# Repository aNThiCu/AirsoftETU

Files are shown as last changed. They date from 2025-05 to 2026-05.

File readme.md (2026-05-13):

Latest board is very promising , i have semi-abandoned the idea of separating the controls and power components from the sensors. The board is now a 4 layer consisting of GND-3.3V-GND-GND copper pours.
Pcb manufacturing at home sadly cannot fullfill my needs for this project , future versions will not be able to be manufactured in house as i have finished some of the testing needed for a complete product.

This revision still is in no way usable , as i haven't been able to test any of the new software implementations. I just finished the firmware and i am about to go on with assembling the rest of the PCB.
I've been using a board with no power electronics until now for testing the signal complementarity and overall logic of the system.

Hardware changes made from the last readme update:

 - added back the high side pmos , board cannot function without it as freewheel diode would blow
 - added back the mode selector phototransistors and led-added a schmitt trigger for hardware debounce
 - added proper gate drivers , MCP1416T-E
 - added some ESD protection diodes on the gates of the power FETS and 12v power rail
 - moved leds to the 3.3v rail
 - modified shape of PCB for better fitment

Software changes made from the last readme update:
   - configurable duty cycle, not tested actual usable range , over 90% is considered 100% due to dead_time limitations
   - configurable dead time ticks for pwm , 1 tick = 200ns , good for different types of power mosfets
   - implemented synchronous rectification to take the burden off the flywheel diode 
   - changed driving logic to permit both PWM and on/off
   - added burst mode capability
   - changed to platformio

What's coming next:
   - finishing testing with new pcb and firmware
   - troubleshooting indicators, buzzer for quick configs in the upcoming settings tab
   - folder with everything needed for direct manufacturing from a factory
   - might do a different type of trigger , either optical of magnetic , for longevity sake , i like the clicking feel of microswitches more though
   
What's been marked done from last readme update:
   - configurable mode selector switch with multiple modes
   - redo of shape for better fitment in V2 gearboxes

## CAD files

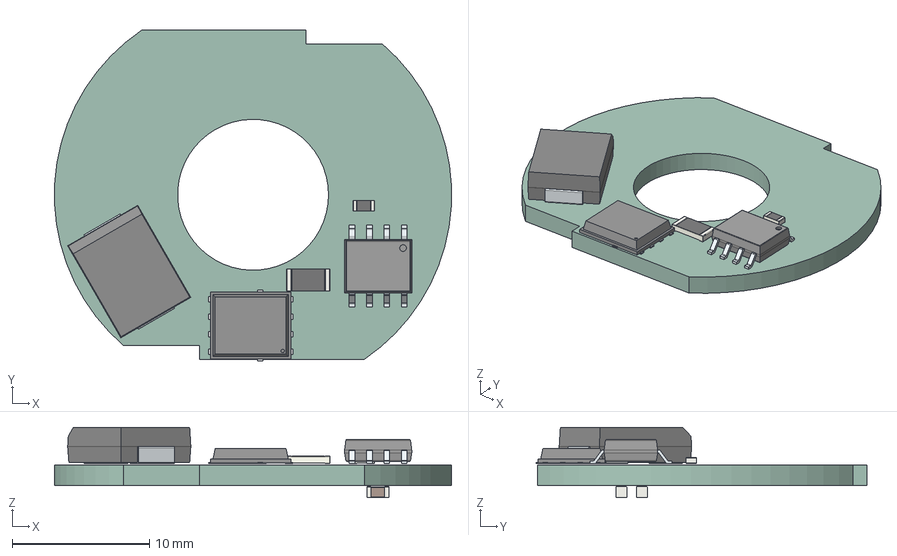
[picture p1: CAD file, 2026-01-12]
PCB_Files/ElectronicTriggerUnit.step
28.9 x 24.1 x 5.13 mm
PinsArrayLR
R_1206_3216Metric
SI7149ADP-T1-GE3
R_0603_1608Metric
FilletPin1
FilletPin2
C_0603_1608Metric x 2
ElectronicTriggerUnit_PCB

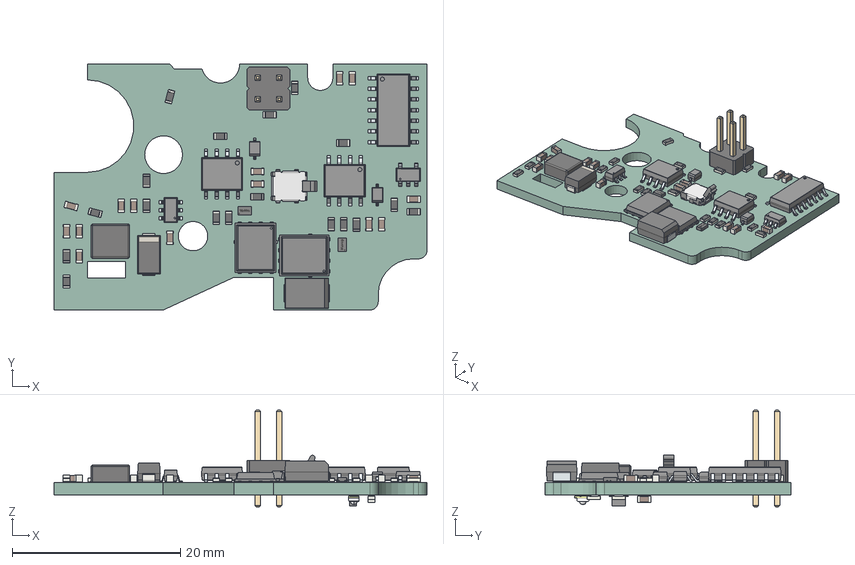
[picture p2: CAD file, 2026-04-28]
PCB_Files/ETU_AIO/ETU_AIO.step
44.4 x 29.3 x 11.5 mm
FilletPinL x 2
FilletPinR x 2
C_0603_1608Metric x 15
R_0603_1608Metric x 20
PinsArrayLR x 4
FilletPin1
FilletPin2
SI7149ADP-T1-GE3 x 2
pins x 14
housing x 2
JJDVDUJ314NCPMRTR
PinsArrayL
PinsArrayR
D_SMA
PinHeader_2x02_P2.54mm_Vertical
L_Chilisin_BMRA00040420
APTD2012SF4C
Pins
ETU_AIO_PCB

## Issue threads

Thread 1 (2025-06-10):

Questions about ETU development

DaniyalV1, 2025-06-10:
Hi there! @aNThiCu

I recently decided to make my own ETU for my CM16 Wildhog GnG Airsoft replica (Version 2 gearbox). I saw that after the "main" section, you continued developing the ETU.

- I know you are still not done, but could you please tell me the issues you have encountered so far?
- I have a LONEX A3 motor, and it falls under the Low TPA category. Does this mean I can't use my motor at all?
- Why did you decide to use sensors inside the gearbox rather than switches? My gearbox currently has tiny switches for the trigger, and replacing them would make it very hard in terms of redesigning the trigger mechanism, etc.
- What is the state of the project?

I would like to further work on this project, and we could collaborate if you would like to.

Thank you!

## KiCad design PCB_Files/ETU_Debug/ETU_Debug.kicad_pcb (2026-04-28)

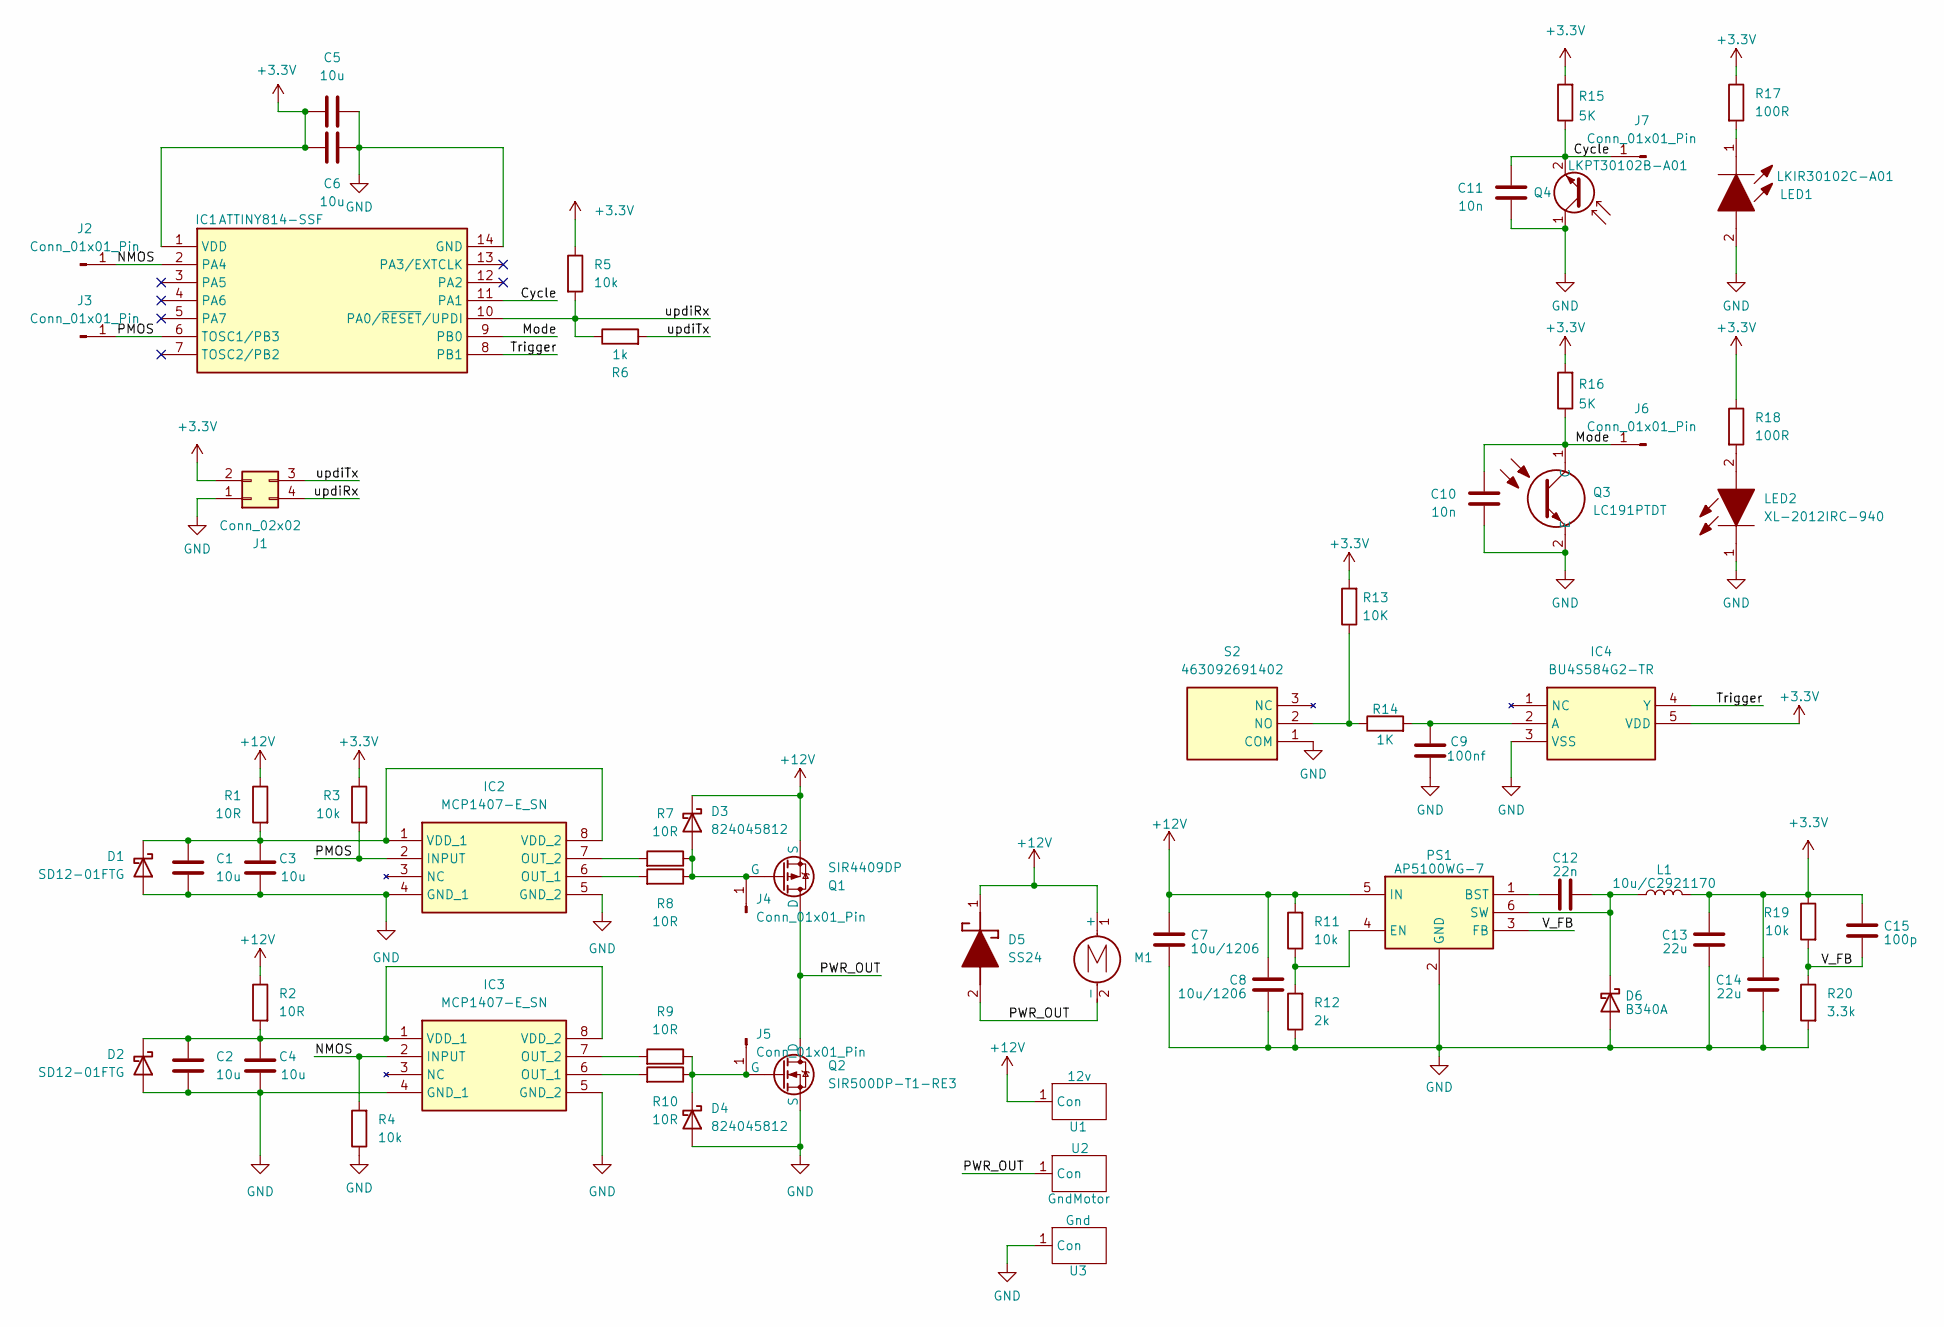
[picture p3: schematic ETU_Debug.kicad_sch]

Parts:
C1, C2, C3, C4, C5, C6: 10u; C_0603_1608Metric
C7, C8: 10u/1206; C_0603_1608Metric; MPN C13585
C9: 100nf; C_0603_1608Metric
C10, C11: 10n; C_0603_1608Metric
C12: 22n; C_0603_1608Metric; MPN C21122
C13, C14: 22u; C_0603_1608Metric; MPN C45783
C15: 100p; C_0603_1608Metric; MPN C1790
D1, D2: SD12-01FTG; SOD2613X114N
D3, D4: 824045812
D5: SS24; DIOM5436X247N; Mouser Part Number 821-SS24
D6: B340A; D_SMA; MPN C3018525
IC1: ATTINY814-SSF; SOIC127P600X175-14N; Mouser Part Number 579-ATTINY814-SSF
IC2, IC3: MCP1407-E_SN; SOIC127P600X175-8N; Mouser Part Number 579-MCP1407-E/SN
IC4: BU4S584G2-TR; SOT95P280X125-5N; Mouser Part Number 755-BU4S584G2-TR
J1: Conn_02x02; PinHeader_2x02_P2.54mm_Vertical
J2, J3, J4, J5, J6, J7: Conn_01x01_Pin; PinHeader_1x01_P2.54mm_Vertical
L1: 10u/C2921170; L_Chilisin_BMRA00040420; MPN C2921170
LED1: LKIR30102C-A01; APA3010P3C; Mouser Part Number 755-CSL1501RW1
LED2: XL-2012IRC-940; LEDC2012X105N; Mouser Part Number 604-APTD2012SF4C
M1: Motor_DC
PS1: AP5100WG-7; SOT95P285X140-6N; Mouser Part Number 621-AP5100WG-7
Q1: SIR4409DP; POWERPAKSO-8
Q2: SIR500DP-T1-RE3; POWERPAKSO-8
Q3: LC191PTDT; AP1608P1CP22; Mouser Part Number 604-AP1608P1C-P22
Q4: LKPT30102B-A01; APA3010P3C
R1, R2, R7, R8, R9, R10: 10R; R_0603_1608Metric
R3, R4, R5: 10k; R_0603_1608Metric
R6: 1k; R_0603_1608Metric
R11, R19: 10k; R_0603_1608Metric; MPN C25804
R12: 2k; R_0603_1608Metric; MPN C22975
R13: 10K; R_0603_1608Metric
R14: 1K; R_0603_1608Metric
R15, R16: 5K; R_0603_1608Metric
R17, R18: 100R; R_0603_1608Metric
R20: 3.3k; R_0603_1608Metric; MPN C22975
S2: 463092691402; Mouser Part Number 710-463092691402
U1: 12v; Copper_Pad
U2: GndMotor; Copper_Pad
U3: Gnd; Copper_Pad

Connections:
+3.3V: C5.1, C6.1, C13.1, C14.1, C15.1, IC1.1 (VDD), IC4.5 (VDD), J1.2, L1.2, R3.1, R5.1, R13.2, R15.2, R16.2, R17.1, R18.1, R19.1
+12V: C7.1, C8.1, D3.1 (K), D5.1 (K), M1.1 (+), PS1.5 (IN), Q1.1 (S), Q1.2 (S), Q1.3 (S), R1.1, R2.1, R11.2, U1.1 (Con)
/Cycle: C11.1, IC1.11 (PA1), J7.1, Q4.2 (E), R15.1
/Mode: C10.1, IC1.9 (PB0), J6.1, Q3.1 (C), R16.1
/NMOS: IC1.2 (PA4), IC3.2 (INPUT), J2.1, R4.2
/PMOS: IC1.6 (TOSC1/PB3), IC2.2 (INPUT), J3.1, R3.2
/PWR_OUT: D5.2 (A), M1.2 (-), Q1.5 (D), Q1.6 (D), Q1.7 (D), Q1.8 (D), Q1.9 (D), Q2.5 (D), Q2.6, Q2.7, Q2.8, Q2.9, U2.1 (Con)
/Trigger: IC1.8 (PB1), IC4.4 (Y)
/V_FB: C15.2, PS1.3 (FB), R19.2, R20.1
/updiRx: IC1.10 (PA0/~RESET/UPDI), J1.4, R5.2, R6.1
/updiTx: J1.3, R6.2
GND: C1.2, C2.2, C3.1, C4.1, C5.2, C6.2, C7.2, C8.2, C9.1, C10.2, C11.2, C13.2, C14.2, D1.2 (A), D2.2 (A), D4.2 (A), D6.2 (A), IC1.14 (GND), IC2.4 (GND_1), IC2.5 (GND_2), IC3.4 (GND_1), IC3.5 (GND_2), IC4.3 (VSS), J1.1, LED1.2, LED2.1, PS1.2 (GND), Q2.1 (S), Q2.2, Q2.3, Q3.2 (E), Q4.1 (C), R4.1, R12.1, R20.2, S2.1 (COM), U3.1 (Con)
unnamed: C1.1, C3.2, D1.1 (K), IC2.1 (VDD_1), IC2.8 (VDD_2), R1.2
unnamed: C2.1, C4.2, D2.1 (K), IC3.1 (VDD_1), IC3.8 (VDD_2), R2.2
unnamed: D3.2 (A), J4.1, Q1.4 (G), R7.1, R8.1
unnamed: D4.1 (K), J5.1, Q2.4 (G), R9.1, R10.1
unnamed: C12.2, D6.1 (K), L1.1, PS1.6 (SW)
unnamed: IC2.6 (OUT_1), R8.2
unnamed: IC2.7 (OUT_2), R7.2
unnamed: IC3.6 (OUT_1), R10.2
unnamed: IC3.7 (OUT_2), R9.2
unnamed: C9.2, IC4.2 (A), R14.2
unnamed: LED1.1, R17.2
unnamed: LED2.2, R18.2
unnamed: C12.1, PS1.1 (BST)
unnamed: PS1.4 (EN), R11.1, R12.2
unnamed: R13.1, R14.1, S2.2 (NO)

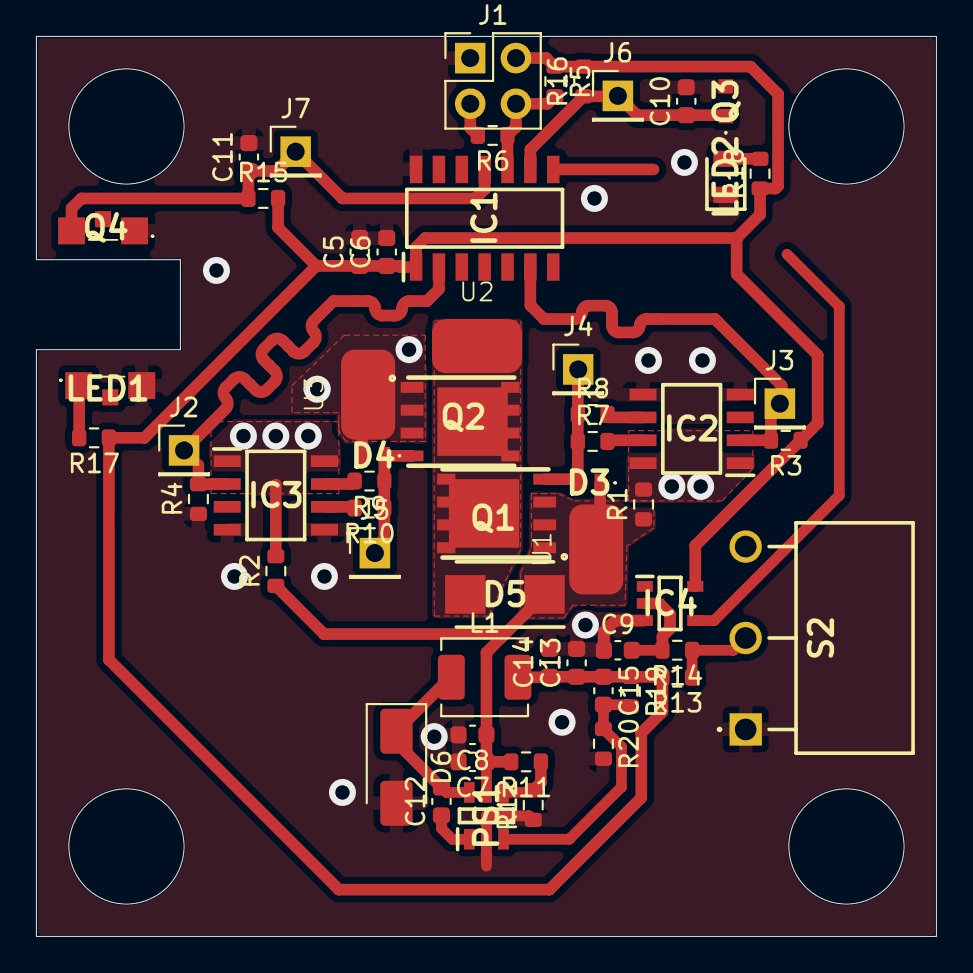
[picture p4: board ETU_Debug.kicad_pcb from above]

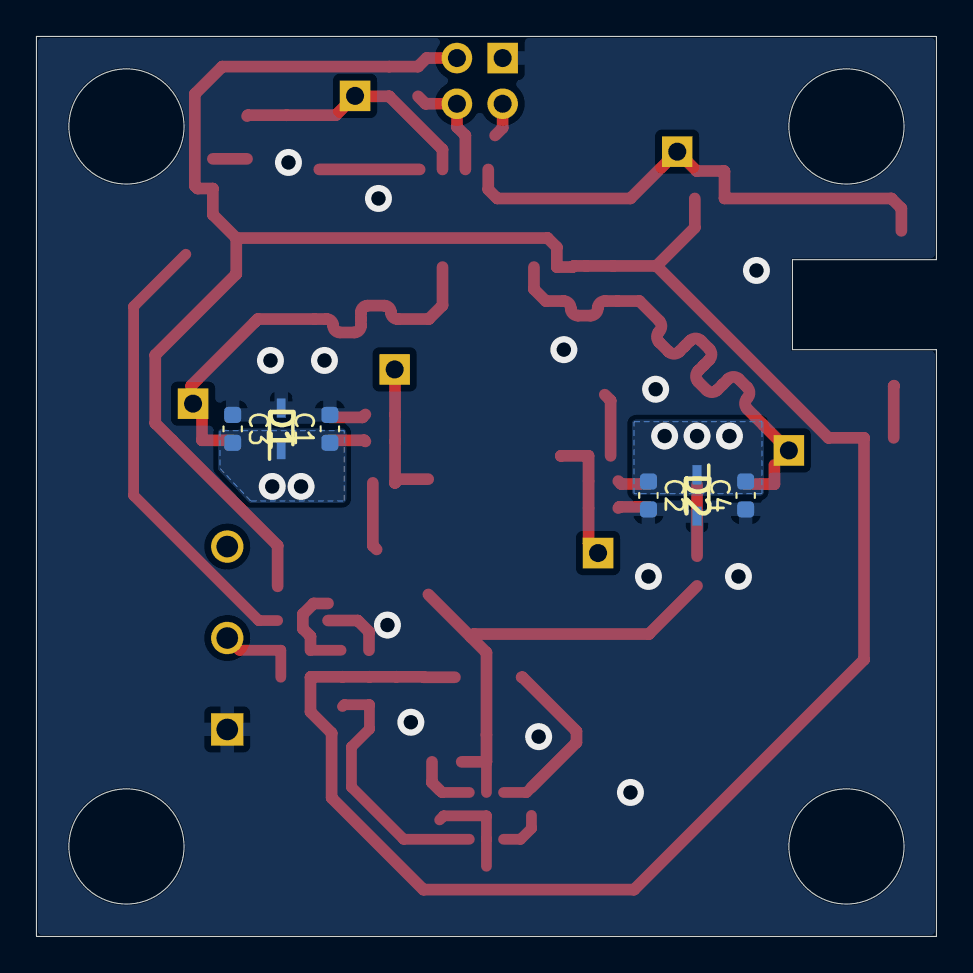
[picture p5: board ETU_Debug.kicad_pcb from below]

Board: 2 copper layers, 50.0 x 50.0 mm, 64 parts (6 on the bottom side), 27 nets.

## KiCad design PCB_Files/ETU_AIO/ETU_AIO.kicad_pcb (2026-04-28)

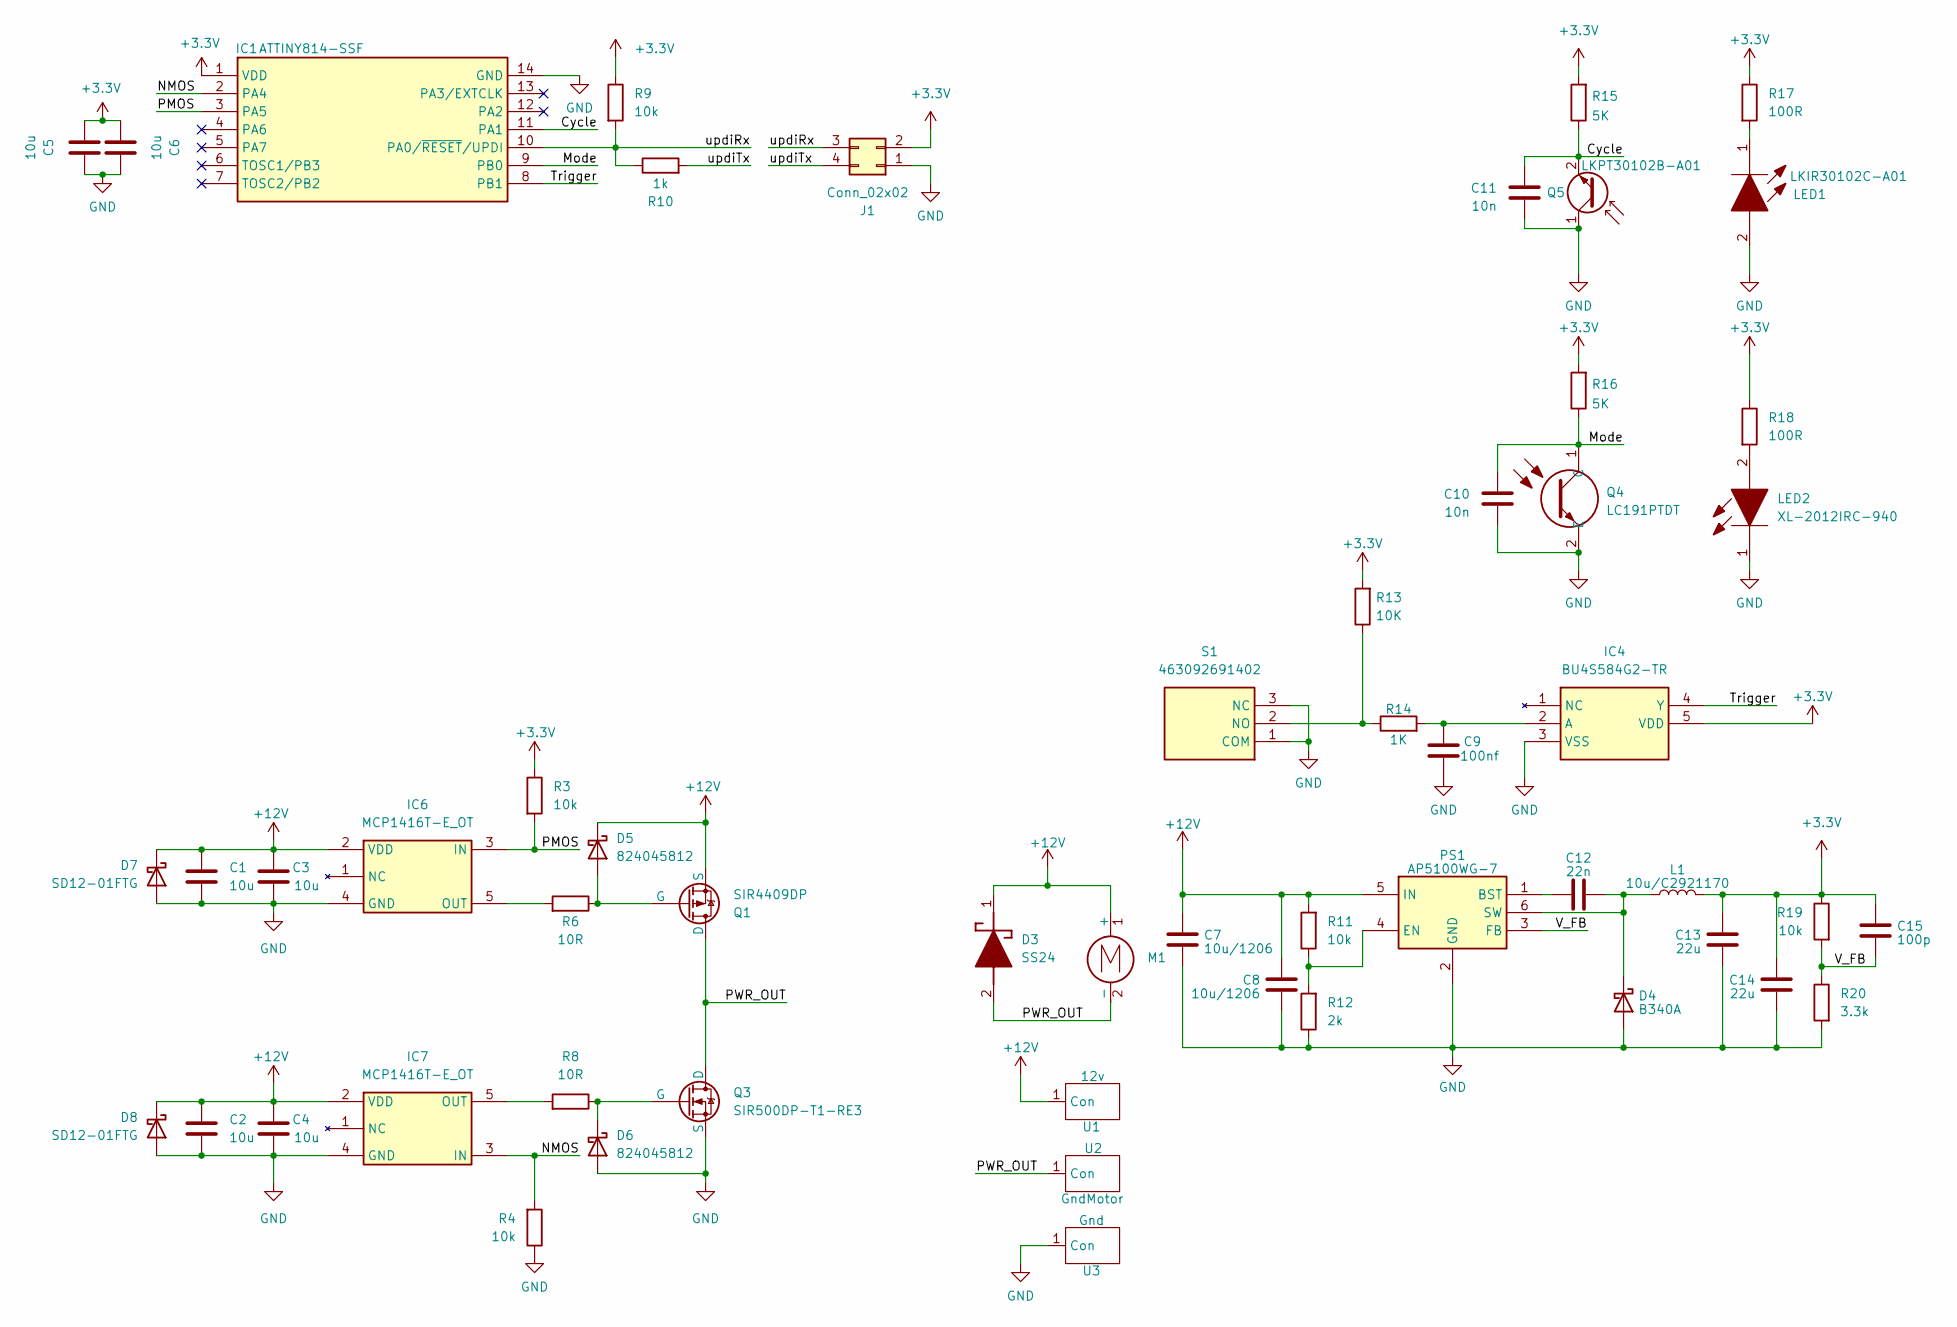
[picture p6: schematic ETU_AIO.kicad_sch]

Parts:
C1, C2, C3, C4, C5, C6: 10u; C_0603_1608Metric
C7, C8: 10u/1206; C_0603_1608Metric; MPN C13585
C9: 100nf; C_0603_1608Metric
C10, C11: 10n; C_0603_1608Metric
C12: 22n; C_0603_1608Metric; MPN C21122
C13, C14: 22u; C_0603_1608Metric; MPN C45783
C15: 100p; C_0603_1608Metric; MPN C1790
D3: SS24; DIOM5436X247N; Mouser Part Number 821-SS24
D4: B340A; D_SMA; MPN C3018525
D5, D6: 824045812
D7, D8: SD12-01FTG; SOD2613X114N
IC1: ATTINY814-SSF; SOIC127P600X175-14N; Mouser Part Number 579-ATTINY814-SSF
IC4: BU4S584G2-TR; SOT95P280X125-5N; Mouser Part Number 755-BU4S584G2-TR
IC6, IC7: MCP1416T-E_OT; SOT95P270X145-5N; Mouser Part Number 579-MCP1416T-E/OT
J1: Conn_02x02; PinHeader_1x04_P2.54mm_Vertical
L1: 10u/C2921170; L_Chilisin_BMRA00040420; MPN C2921170
LED1: LKIR30102C-A01; APA3010P3C; Mouser Part Number 755-CSL1501RW1
LED2: XL-2012IRC-940; LEDC2012X105N; Mouser Part Number 604-APTD2012SF4C
M1: Motor_DC
PS1: AP5100WG-7; SOT95P285X140-6N; Mouser Part Number 621-AP5100WG-7
Q1: SIR4409DP; POWERPAKSO-8
Q3: SIR500DP-T1-RE3; POWERPAKSO-8
Q4: LC191PTDT; AP1608P1CP22; Mouser Part Number 604-AP1608P1C-P22
Q5: LKPT30102B-A01; APA3010P3C
R3, R4, R9: 10k; R_0603_1608Metric
R6, R8: 10R; R_0603_1608Metric
R10: 1k; R_0603_1608Metric
R11, R19: 10k; R_0603_1608Metric; MPN C25804
R12: 2k; R_0603_1608Metric; MPN C22975
R13: 10K; R_0603_1608Metric
R14: 1K; R_0603_1608Metric
R15, R16: 5K; R_0603_1608Metric
R17, R18: 100R; R_0603_1608Metric
R20: 3.3k; R_0603_1608Metric; MPN C22975
S1: 463092691402; Mouser Part Number 710-463092691402
U1: 12v; Copper_Pad
U2: GndMotor; Copper_Pad
U3: Gnd; Copper_Pad

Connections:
+3.3V: C5.1, C6.1, C13.1, C14.1, C15.1, IC1.1 (VDD), IC4.5 (VDD), J1.2, L1.2, R3.1, R9.1, R13.2, R15.2, R16.2, R17.1, R18.1, R19.1
+12V: C1.1, C2.1, C3.2, C4.2, C7.1, C8.1, D3.1 (K), D5.1 (K), D7.1 (K), D8.1 (K), IC6.2 (VDD), IC7.2 (VDD), M1.1 (+), PS1.5 (IN), Q1.1 (S), Q1.2 (S), Q1.3 (S), R11.2, U1.1 (Con_1)
/Cycle: C11.1, IC1.11 (PA1), Q5.2 (E), R15.1
/Mode: C10.1, IC1.9 (PB0), Q4.1 (C), R16.1
/NMOS: IC1.2 (PA4), IC7.3 (IN), R4.2
/PMOS: IC1.3 (PA5), IC6.3 (IN), R3.2
/PWR_OUT: D3.2 (A), M1.2 (-), Q1.5 (D), Q1.6 (D), Q1.7 (D), Q1.8 (D), Q1.9 (D), Q3.5 (D), Q3.6, Q3.7, Q3.8, Q3.9, U2.1 (Con_1)
/Trigger: IC1.8 (PB1), IC4.4 (Y)
/V_FB: C15.2, PS1.3 (FB), R19.2, R20.1
/updiRx: IC1.10 (PA0/~RESET/UPDI), J1.3, R9.2, R10.1
/updiTx: J1.4, R10.2
GND: C1.2, C2.2, C3.1, C4.1, C5.2, C6.2, C7.2, C8.2, C9.1, C10.2, C11.2, C13.2, C14.2, D4.2 (A), D6.2 (A), D7.2 (A), D8.2 (A), IC1.14 (GND), IC4.3 (VSS), IC6.4 (GND), IC7.4 (GND), J1.1, LED1.2, LED2.1, PS1.2 (GND), Q3.1 (S), Q3.2, Q3.3, Q4.2 (E), Q5.1 (C), R4.1, R12.1, R20.2, S1.1 (COM), S1.3 (NC), U3.1 (Con_1)
unnamed: C12.2, D4.1 (K), L1.1, PS1.6 (SW)
unnamed: D5.2 (A), Q1.4 (G), R6.1
unnamed: D6.1 (K), Q3.4 (G), R8.1
unnamed: C9.2, IC4.2 (A), R14.2
unnamed: IC6.5 (OUT), R6.2
unnamed: IC7.5 (OUT), R8.2
unnamed: LED1.1, R17.2
unnamed: LED2.2, R18.2
unnamed: C12.1, PS1.1 (BST)
unnamed: PS1.4 (EN), R11.1, R12.2
unnamed: R13.1, R14.1, S1.2 (NO)

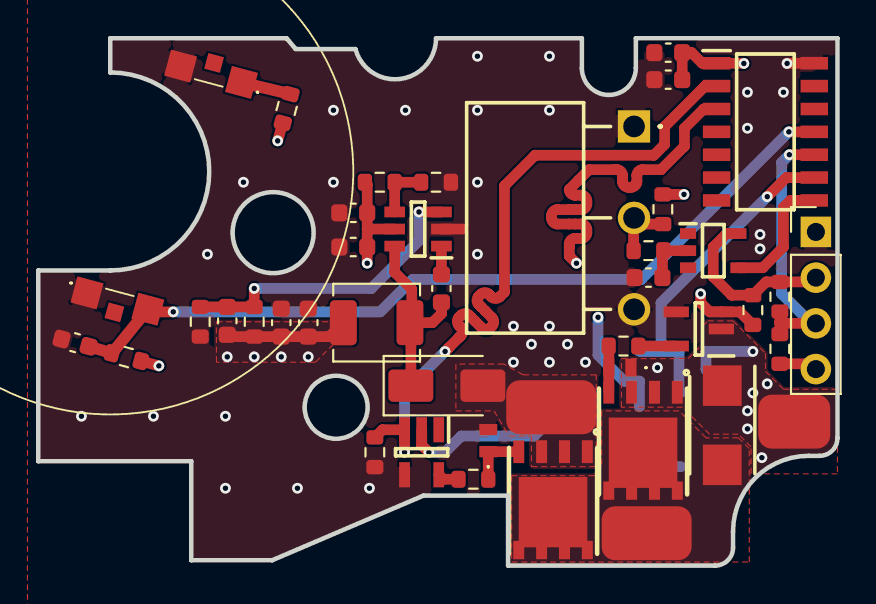
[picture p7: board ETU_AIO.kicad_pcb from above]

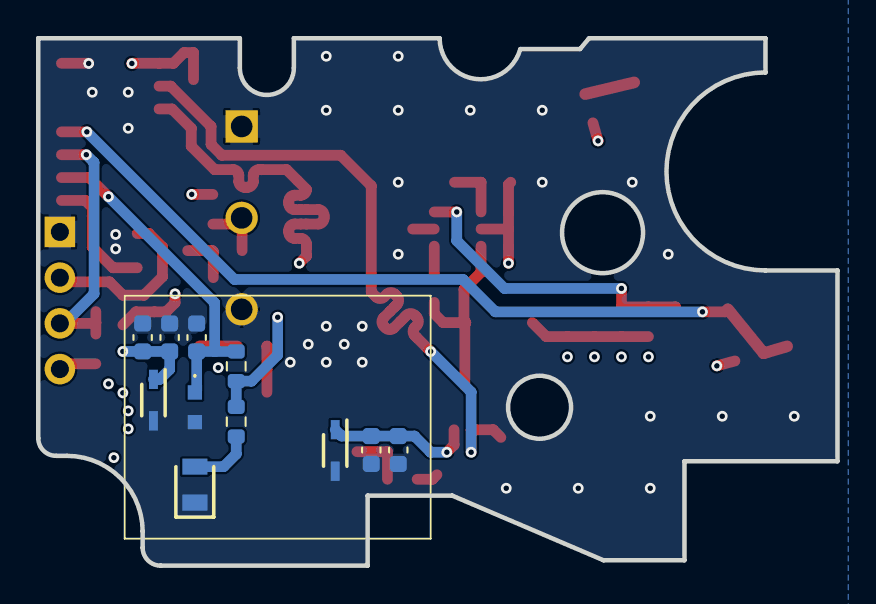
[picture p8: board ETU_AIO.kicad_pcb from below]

Board: 4 copper layers, 44.4 x 29.3 mm, 54 parts (11 on the bottom side), 23 nets.

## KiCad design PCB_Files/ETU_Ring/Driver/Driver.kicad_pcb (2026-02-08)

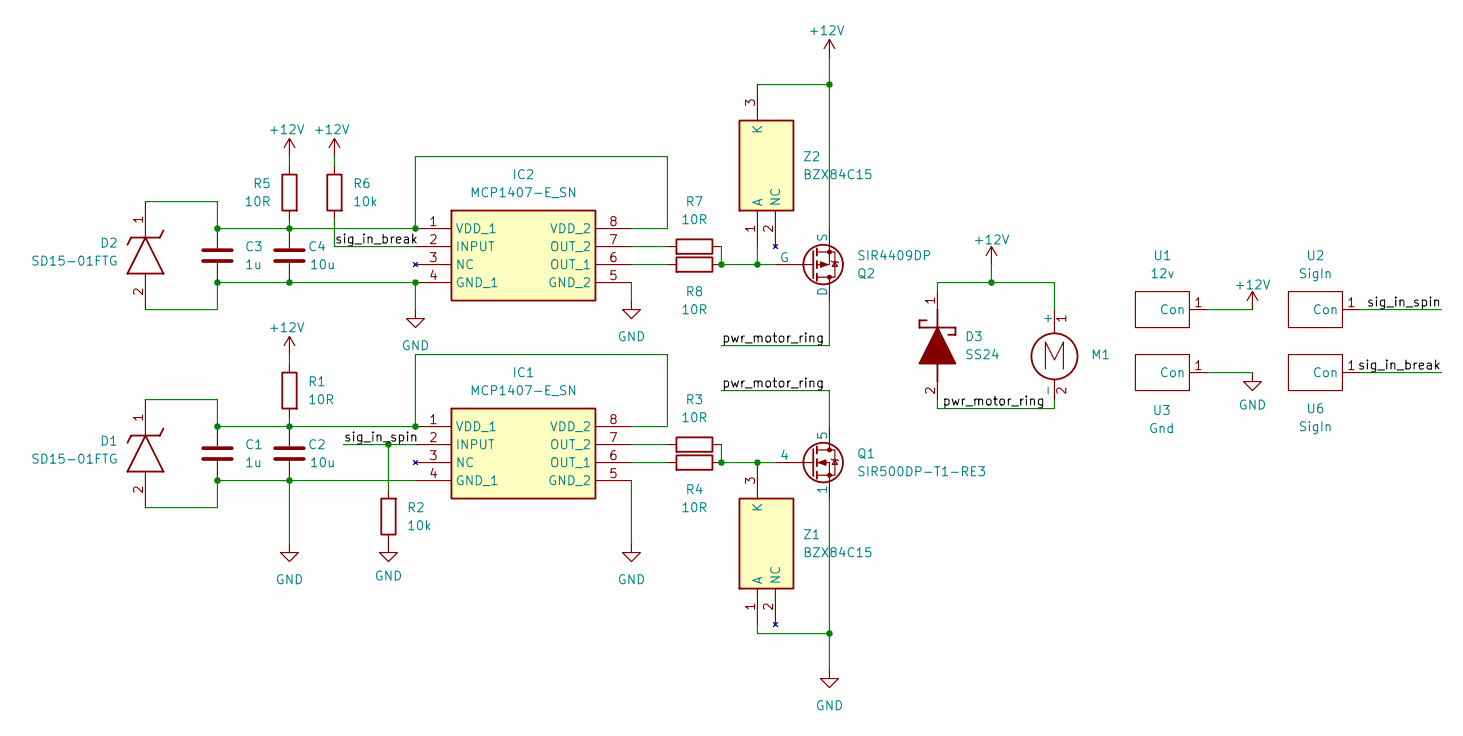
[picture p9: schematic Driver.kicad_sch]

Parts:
C1, C3: 1u; C_0603_1608Metric
C2, C4: 10u; C_0603_1608Metric
D1, D2: SD15-01FTG; SOD2613X114N; Manufacturer_Part_Number SD15-01FTG
D3: SS24; DIOM5436X247N; Mouser Part Number 821-SS24
IC1, IC2: MCP1407-E_SN; SOIC127P600X175-8N; Mouser Part Number 579-MCP1407-E/SN
M1: Motor_DC
Q1: SIR500DP-T1-RE3; POWERPAKSO-8
Q2: SIR4409DP; POWERPAKSO-8
R1, R3, R4, R5, R7, R8: 10R; R_0603_1608Metric
R2, R6: 10k; R_0603_1608Metric
U1: 12v; Copper_Pad
U2, U6: SigIn; Copper_Pad
U3: Gnd; Copper_Pad
Z1, Z2: BZX84C15; SOT96P260X140-3N; Manufacturer_Part_Number BZX84C15

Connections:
+12V: D3.1 (K), M1.1 (+), Q2.1 (S), Q2.2 (S), Q2.3 (S), R1.1, R5.1, R6.1, U1.1 (Con), Z2.2 (NC), Z2.3 (K)
/pwr_motor_ring: D3.2 (A), M1.2 (-), Q1.5, Q1.6, Q1.7, Q1.8, Q1.9, Q2.5 (D), Q2.6 (D), Q2.7 (D), Q2.8 (D), Q2.9 (D)
/sig_in_break: IC2.2 (INPUT), R6.2, U6.1 (Con)
/sig_in_spin: IC1.2 (INPUT), R2.2, U2.1 (Con)
GND: C1.2, C2.1, C3.2, C4.1, D1.2 (A), D2.2 (A), IC1.4 (GND_1), IC1.5 (GND_2), IC2.4 (GND_1), IC2.5 (GND_2), Q1.1, Q1.2, Q1.3, R2.1, U3.1 (Con), Z1.1 (A)
unnamed: C1.1, C2.2, D1.1 (K), IC1.1 (VDD_1), IC1.8 (VDD_2), R1.2
unnamed: C3.1, C4.2, D2.1 (K), IC2.1 (VDD_1), IC2.8 (VDD_2), R5.2
unnamed: IC1.6 (OUT_1), R4.2
unnamed: IC1.7 (OUT_2), R3.2
unnamed: IC2.6 (OUT_1), R8.2
unnamed: IC2.7 (OUT_2), R7.2
unnamed: Q2.4 (G), R7.1, R8.1, Z2.1 (A)
unnamed: Q1.4, R3.1, R4.1, Z1.3 (K)

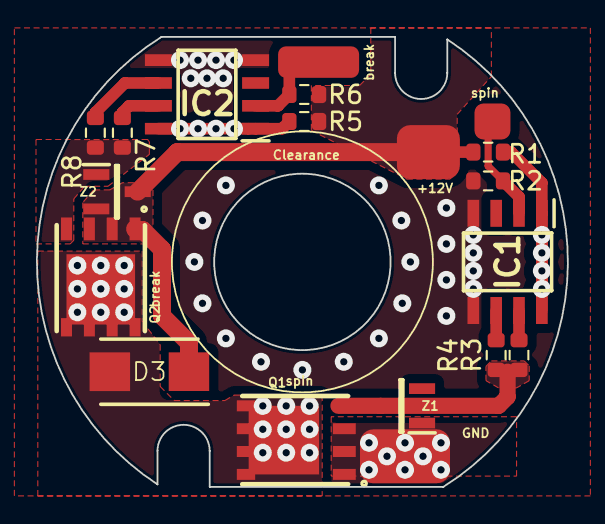
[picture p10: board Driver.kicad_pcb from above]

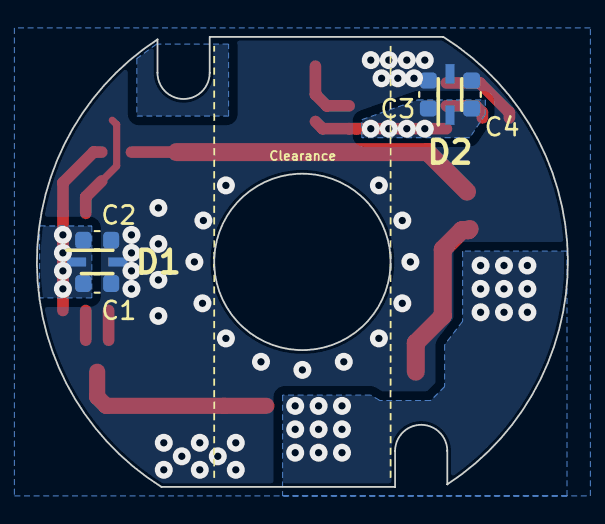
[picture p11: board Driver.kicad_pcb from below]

Board: 2 copper layers, 29.5 x 25.0 mm, 25 parts (6 on the bottom side), 13 nets.

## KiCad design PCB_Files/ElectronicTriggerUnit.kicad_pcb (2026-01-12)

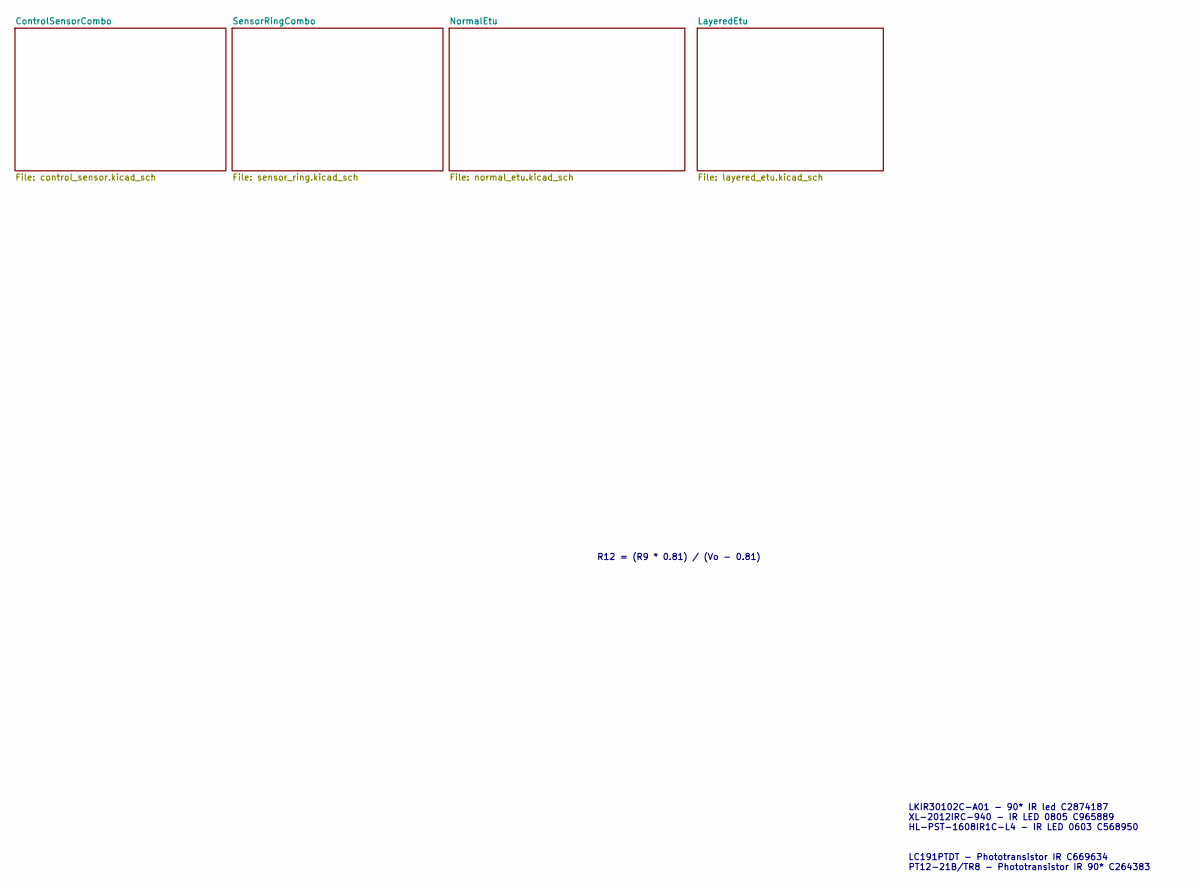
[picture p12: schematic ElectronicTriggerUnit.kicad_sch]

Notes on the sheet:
R12 = (R9 * 0.81) / (Vo - 0.81)
LKIR30102C-A01 - 90* IR led C2874187 XL-2012IRC-940 - IR LED 0805 C965889 HL-PST-1608IR1C-L4 - IR LED 0603 C568950 LC191PTDT - Phototransistor IR C669634 PT12-21B/TR8 - Phototransistor IR 90* C264383

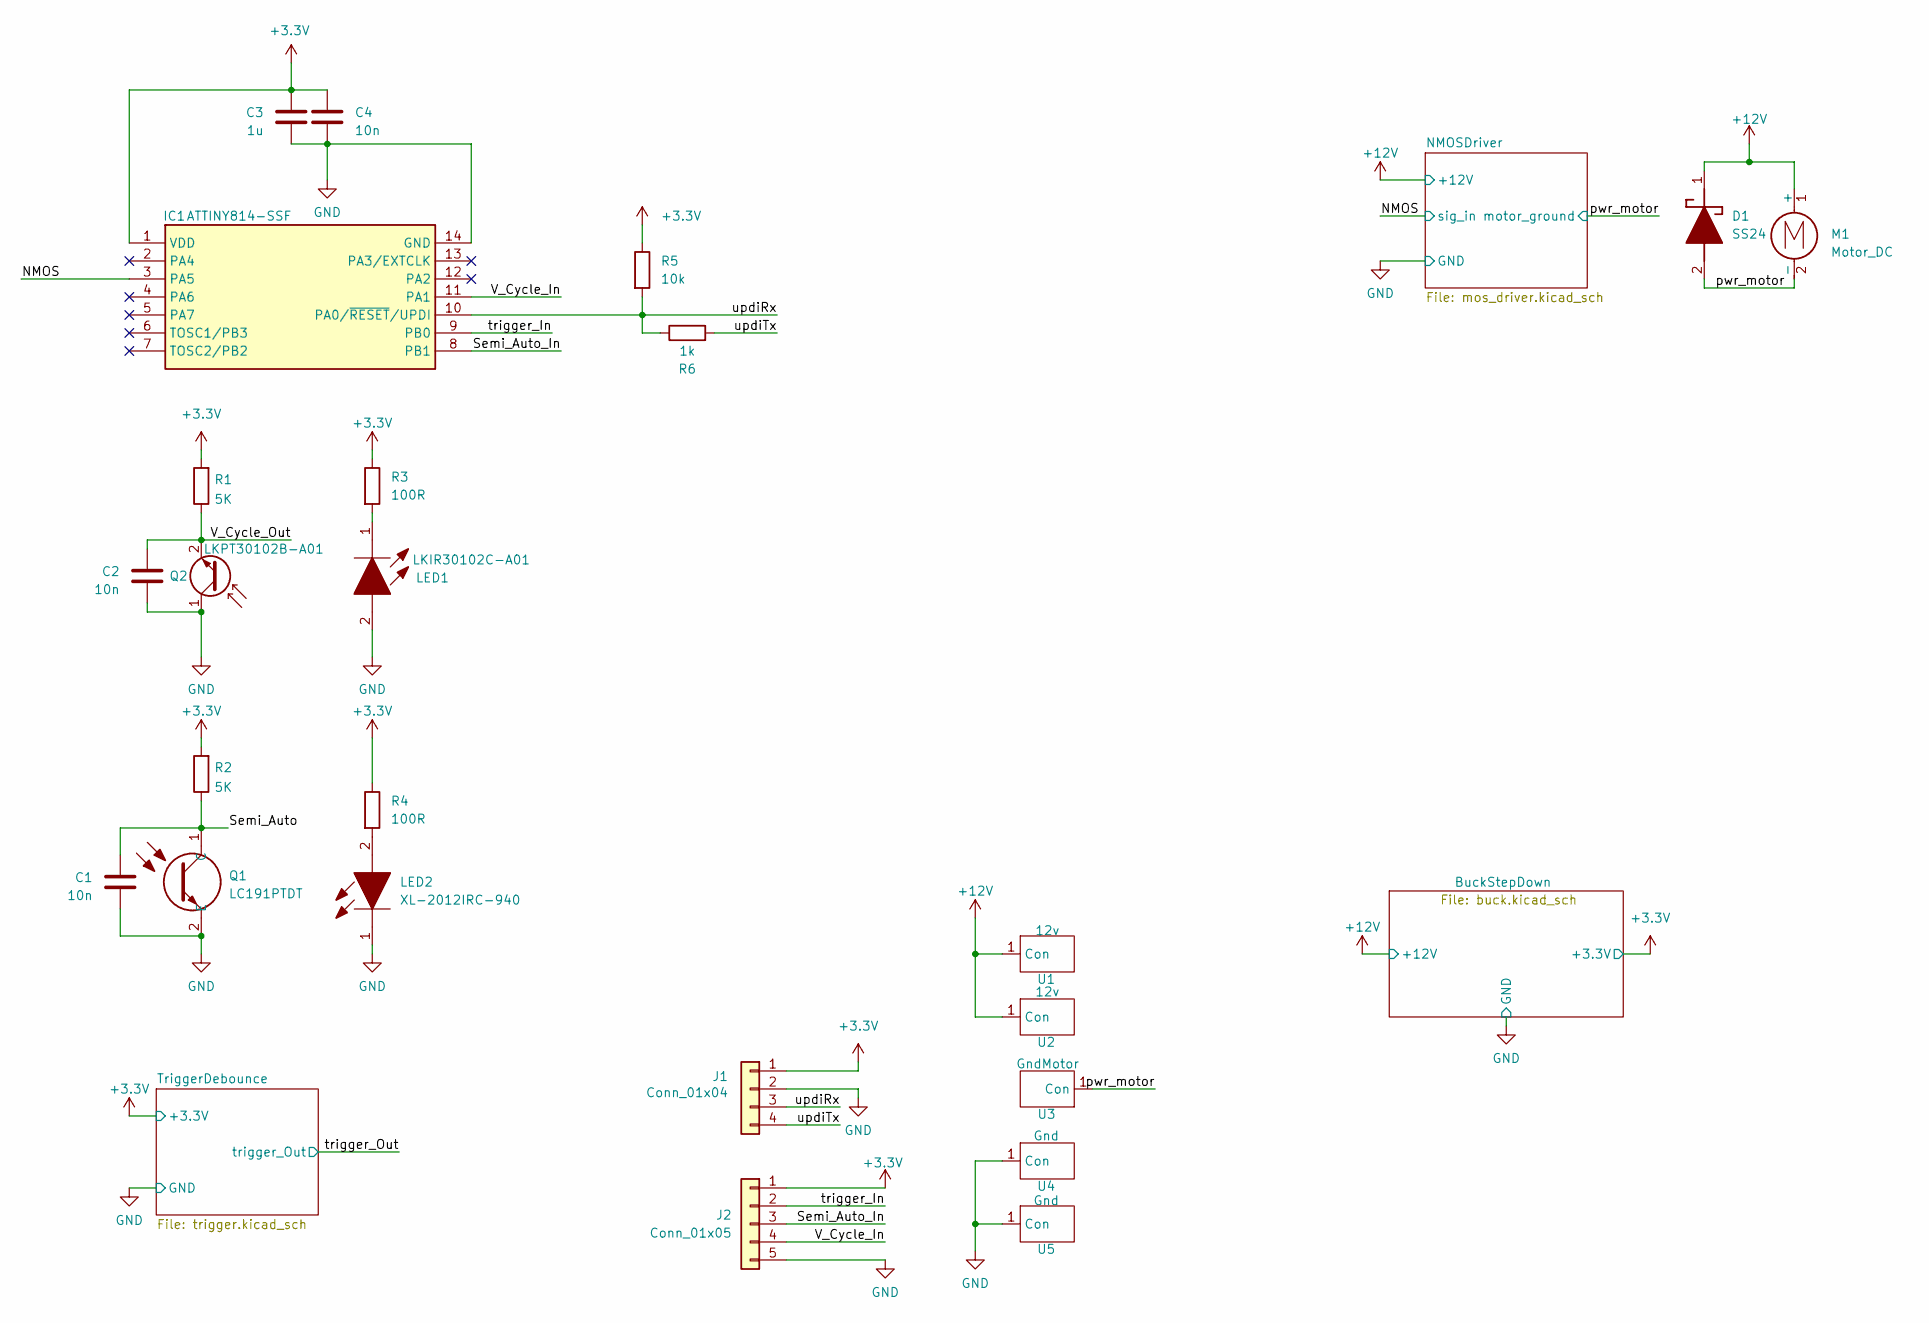
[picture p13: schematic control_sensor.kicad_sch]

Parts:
C1, C2, C4: 10n; C_0603_1608Metric
C3: 1u; C_0603_1608Metric
D1: SS24; DIOM5436X247N; Mouser Part Number 821-SS24
IC1: ATTINY814-SSF; SOIC127P600X175-14N; Mouser Part Number 579-ATTINY814-SSF
J1: Conn_01x04; PinHeader_1x04_P2.54mm_Vertical
J2: Conn_01x05; PinSocket_1x05_P2.54mm_Vertical
LED1: LKIR30102C-A01; APA3010P3C; Mouser Part Number 755-CSL1501RW1
LED2: XL-2012IRC-940; LEDC2012X105N; Mouser Part Number 604-APTD2012SF4C
M1: Motor_DC
Q1: LC191PTDT; AP1608P1CP22; Mouser Part Number 604-AP1608P1C-P22
Q2: LKPT30102B-A01; APA3010P3C
R1, R2: 5K; R_0603_1608Metric
R3, R4: 100R; R_0603_1608Metric
R5: 10k; R_0603_1608Metric
R6: 1k; R_0603_1608Metric
U1, U2: 12v; Copper_Pad
U3: GndMotor; Copper_Pad
U4, U5: Gnd; Copper_Pad

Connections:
+3.3V: C3.1, C4.1, IC1.1 (VDD), J1.1, J2.1, R1.2, R2.2, R3.1, R4.1, R5.1; also elsewhere on the board
+12V: D1.1 (K), M1.1 (+), U1.1 (Con), U2.1 (Con); also elsewhere on the board
/ControlSensorCombo/NMOS: IC1.3 (PA5); also elsewhere on the board
/ControlSensorCombo/Semi_Auto: C1.1, Q1.1 (C), R2.1
/ControlSensorCombo/Semi_Auto_In: IC1.8 (PB1), J2.3
/ControlSensorCombo/V_Cycle_In: IC1.11 (PA1), J2.4
/ControlSensorCombo/V_Cycle_Out: C2.1, Q2.2 (E), R1.1
/ControlSensorCombo/pwr_motor: D1.2 (A), M1.2 (-), U3.1 (Con); also elsewhere on the board
/ControlSensorCombo/trigger_In: IC1.9 (PB0), J2.2
/ControlSensorCombo/updiRx: IC1.10 (PA0/~RESET/UPDI), J1.3, R5.2, R6.1
/ControlSensorCombo/updiTx: J1.4, R6.2
GND: C1.2, C2.2, C3.2, C4.2, IC1.14 (GND), J1.2, J2.5, LED1.2, LED2.1, Q1.2 (E), Q2.1 (C), U4.1 (Con), U5.1 (Con); also elsewhere on the board
unnamed: LED1.1, R3.2
unnamed: LED2.2, R4.2

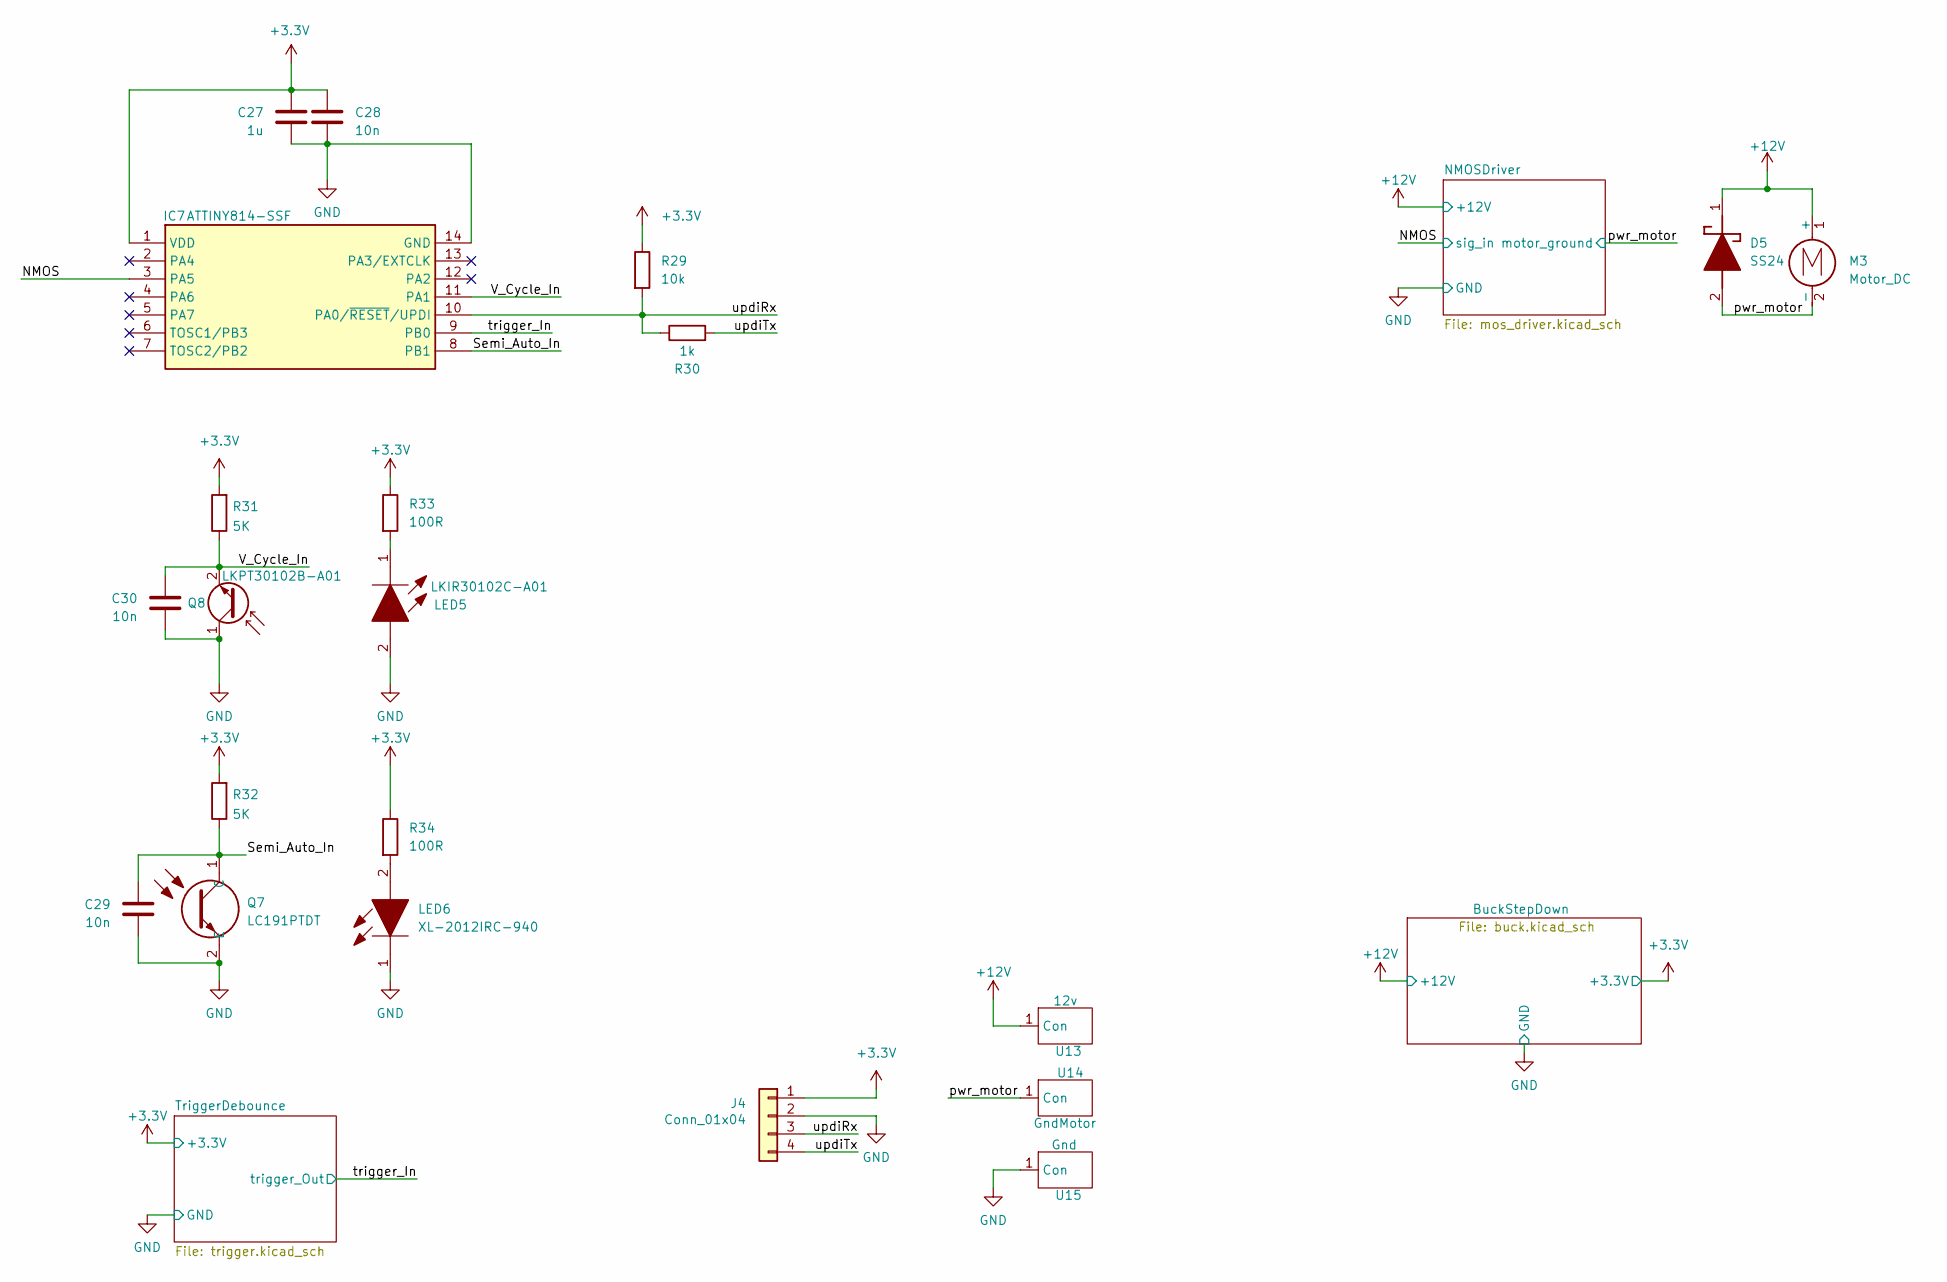
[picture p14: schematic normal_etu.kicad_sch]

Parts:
C27: 1u; C_0603_1608Metric
C28, C29, C30: 10n; C_0603_1608Metric
D5: SS24; DIOM5436X247N; Mouser Part Number 821-SS24
IC7: ATTINY814-SSF; SOIC127P600X175-14N; Mouser Part Number 579-ATTINY814-SSF
J4: Conn_01x04; PinHeader_1x04_P2.54mm_Vertical
LED5: LKIR30102C-A01; APA3010P3C; Mouser Part Number 755-CSL1501RW1
LED6: XL-2012IRC-940; LEDC2012X105N; Mouser Part Number 604-APTD2012SF4C
M3: Motor_DC
Q7: LC191PTDT; AP1608P1CP22; Mouser Part Number 604-AP1608P1C-P22
Q8: LKPT30102B-A01; APA3010P3C
R29: 10k; R_0603_1608Metric
R30: 1k; R_0603_1608Metric
R31, R32: 5K; R_0603_1608Metric
R33, R34: 100R; R_0603_1608Metric
U13: 12v; Copper_Pad
U14: GndMotor; Copper_Pad
U15: Gnd; Copper_Pad

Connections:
+3.3V: C27.1, C28.1, IC7.1 (VDD), J4.1, R29.1, R31.2, R32.2, R33.1, R34.1; also elsewhere on the board
+12V: D5.1 (K), M3.1 (+), U13.1 (Con); also elsewhere on the board
/NormalEtu/NMOS: IC7.3 (PA5); also elsewhere on the board
/NormalEtu/Semi_Auto_In: C29.1, IC7.8 (PB1), Q7.1 (C), R32.1
/NormalEtu/V_Cycle_In: C30.1, IC7.11 (PA1), Q8.2 (E), R31.1
/NormalEtu/pwr_motor: D5.2 (A), M3.2 (-), U14.1 (Con); also elsewhere on the board
/NormalEtu/trigger_In: IC7.9 (PB0); also elsewhere on the board
/NormalEtu/updiRx: IC7.10 (PA0/~RESET/UPDI), J4.3, R29.2, R30.1
/NormalEtu/updiTx: J4.4, R30.2
GND: C27.2, C28.2, C29.2, C30.2, IC7.14 (GND), J4.2, LED5.2, LED6.1, Q7.2 (E), Q8.1 (C), U15.1 (Con); also elsewhere on the board
unnamed: LED5.1, R33.2
unnamed: LED6.2, R34.2

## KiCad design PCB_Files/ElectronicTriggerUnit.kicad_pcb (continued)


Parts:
C16, C17, C19: 10n; C_0603_1608Metric
C18: 1u; C_0603_1608Metric
D2: SS24; DIOM5436X247N; Mouser Part Number 821-SS24
IC5: ATTINY814-SSF; SOIC127P600X175-14N; Mouser Part Number 579-ATTINY814-SSF
J3: Conn_01x04; PinHeader_1x04_P2.54mm_Vertical
LED3: LKIR30102C-A01; APA3010P3C; Mouser Part Number 755-CSL1501RW1
LED4: XL-2012IRC-940; LEDC2012X105N; Mouser Part Number 604-APTD2012SF4C
M2: Motor_DC
Q5: LC191PTDT; AP1608P1CP22; Mouser Part Number 604-AP1608P1C-P22
Q6: LKPT30102B-A01; APA3010P3C
R17, R18: 5K; R_0603_1608Metric
R19, R20: 100R; R_0603_1608Metric
R21: 10k; R_0603_1608Metric
R22: 1k; R_0603_1608Metric
U6, U9: 12v; Copper_Pad
U7: SigIn; Copper_Pad
U8, U10: Gnd; Copper_Pad
U11: GndMotor; Copper_Pad

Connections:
+3.3V: C18.1, C19.1, IC5.1 (VDD), J3.1, R17.2, R18.2, R19.1, R20.1, R21.1; also elsewhere on the board
+12V: D2.1 (K), M2.1 (+), U6.1 (Con), U9.1 (Con); also elsewhere on the board
/SensorRingCombo/Semi_Auto: C16.1, IC5.8 (PB1), Q5.1 (C), R18.1
/SensorRingCombo/V_Cycle: C17.1, IC5.11 (PA1), Q6.2 (E), R17.1
/SensorRingCombo/pwr_motor_ring: D2.2 (A), M2.2 (-); also elsewhere on the board
/SensorRingCombo/sigIn: U7.1 (Con); also elsewhere on the board
/SensorRingCombo/sigOut: IC5.3 (PA5), U11.1 (Con)
/SensorRingCombo/trigger: IC5.9 (PB0); also elsewhere on the board
/SensorRingCombo/updiRx: IC5.10 (PA0/~RESET/UPDI), J3.4, R21.2, R22.1
/SensorRingCombo/updiTx: J3.3, R22.2
GND: C16.2, C17.2, C18.2, C19.2, IC5.14 (GND), J3.2, LED3.2, LED4.1, Q5.2 (E), Q6.1 (C), U8.1 (Con), U10.1 (Con); also elsewhere on the board
unnamed: LED3.1, R19.2
unnamed: LED4.2, R20.2


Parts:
C46, C47: 10n; C_0603_1608Metric
C48: 1u; C_0603_1608Metric
C49: 100n; C_0603_1608Metric
D9: STPS5L60S; DIOM8059X265N; Manufacturer_Part_Number STPS5L60S
IC10: ATTINY814-SSF; SOIC127P600X175-14N; Mouser Part Number 579-ATTINY814-SSF
J5, J6: Conn_01x04; PinHeader_1x04_P2.54mm_Vertical
J7, J8, J9, J10: Conn_01x01; PinHeader_1x01_P2.54mm_Vertical
LED7: LKIR30102C-A01; APA3010P3C; Mouser Part Number 755-CSL1501RW1
LED8: XL-2012IRC-940; LEDC2012X105N; Mouser Part Number 604-APTD2012SF4C
M4: Motor_DC
Q10: LC191PTDT; AP1608P1CP22; Mouser Part Number 604-AP1608P1C-P22
Q11: LKPT30102B-A01; APA3010P3C
R47, R48: 5K; R_0603_1608Metric
R49, R50: 100R; R_0603_1608Metric
R51: 10k; R_0603_1608Metric
R52: 1k; R_0603_1608Metric
TP1, TP2, TP3, TP4: TestPoint; TestPoint_Loop_D1.80mm_Drill1.0mm_Beaded
U12: 12v; Copper_Pad
U16: GndMotor; Copper_Pad
U17: Gnd; Copper_Pad

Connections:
+3.3V: C48.1, C49.1, IC10.1 (VDD), J5.1, J6.1, J9.1, R47.2, R48.2, R49.1, R50.1, R51.1; also elsewhere on the board
+12V: D9.1 (K), M4.1 (+), U12.1 (Con); also elsewhere on the board
/LayeredEtu/NMOS: IC10.3 (PA5), J7.1, J8.1, TP2.1; also elsewhere on the board
/LayeredEtu/Semi_Auto_In: C46.1, IC10.8 (PB1), Q10.1 (C), R48.1, TP1.1
/LayeredEtu/V_Cycle_In: C47.1, IC10.11 (PA1), Q11.2 (E), R47.1, TP4.1
/LayeredEtu/pwr_motor: D9.2 (A), M4.2 (-), U16.1 (Con); also elsewhere on the board
/LayeredEtu/trigger_In: IC10.9 (PB0), TP3.1; also elsewhere on the board
/LayeredEtu/updiRx: IC10.10 (PA0/~RESET/UPDI), J5.3, J6.3, R51.2, R52.1
/LayeredEtu/updiTx: J5.4, J6.4, R52.2
GND: C46.2, C47.2, C48.2, C49.2, IC10.14 (GND), J5.2, J6.2, J10.1, LED7.2, LED8.1, Q10.2 (E), Q11.1 (C), U17.1 (Con); also elsewhere on the board
unnamed: LED7.1, R49.2
unnamed: LED8.2, R50.2


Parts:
C15: 100nf; C_0603_1608Metric
IC4: BU4S584G2-TR; SOT95P280X125-5N; Mouser Part Number 755-BU4S584G2-TR
R15: 10K; R_0603_1608Metric
R16: 1K; R_0603_1608Metric
S1: Trigger; 463092691402; Mouser Part Number 710-463092691402

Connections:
+3.3V: IC4.5 (VDD), R15.2; also elsewhere on the board
/ControlSensorCombo/trigger_Out: IC4.4 (Y)
GND: C15.1, IC4.3 (VSS), S1.1 (COM), S1.3 (NC); also elsewhere on the board
unnamed: C15.2, IC4.2 (A), R16.2
unnamed: R15.1, R16.1, S1.2 (NO)

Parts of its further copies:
C26, C31, C52: 100nf; C_0603_1608Metric
IC6, IC8, IC12: BU4S584G2-TR; SOT95P280X125-5N; Mouser Part Number 755-BU4S584G2-TR
R27, R35, R55: 10K; R_0603_1608Metric
R28, R36, R56: 1K; R_0603_1608Metric
S2, S3, S4: Trigger; 463092691402; Mouser Part Number 710-463092691402

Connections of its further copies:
+3.3V: IC6.5 (VDD), IC8.5 (VDD), IC12.5 (VDD), R27.2, R35.2, R55.2; also elsewhere on the board
/LayeredEtu/trigger_In: IC12.4 (Y); also elsewhere on the board
/NormalEtu/trigger_In: IC8.4 (Y); also elsewhere on the board
/SensorRingCombo/trigger: IC6.4 (Y); also elsewhere on the board
GND: C26.1, C31.1, C52.1, IC6.3 (VSS), IC8.3 (VSS), IC12.3 (VSS), S2.1 (COM), S2.3 (NC), S3.1 (COM), S3.3 (NC), S4.1 (COM), S4.3 (NC); also elsewhere on the board
unnamed: C26.2, IC6.2 (A), R28.2
unnamed: C31.2, IC8.2 (A), R36.2
unnamed: C52.2, IC12.2 (A), R56.2
unnamed: R27.1, R28.1, S2.2 (NO)
unnamed: R35.1, R36.1, S3.2 (NO)
unnamed: R55.1, R56.1, S4.2 (NO)


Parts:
C20, C21: 10u/1206; C_0603_1608Metric; MPN C13585
C22: 22n; C_0603_1608Metric; MPN C21122
C23, C24: 22u; C_0603_1608Metric; MPN C45783
C25: 100p; C_0603_1608Metric; MPN C1790
D4: B340A; D_SMA; MPN C3018525
L2: 10u/C2921170; L_Chilisin_BMRA00040420; MPN C2921170
PS2: AP5100WG-7; SOT95P285X140-6N; Mouser Part Number 621-AP5100WG-7
R23, R25: 10k; R_0603_1608Metric; MPN C25804
R24: 2k; R_0603_1608Metric; MPN C22975
R26: 3.3k; R_0603_1608Metric; MPN C22975

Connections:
+3.3V: C23.1, C24.1, C25.1, L2.2, R25.1; also elsewhere on the board
+12V: C20.1, C21.1, PS2.5 (IN), R23.2; also elsewhere on the board
/SensorRingCombo/BuckStepDown1/V_FB: C25.2, PS2.3 (FB), R25.2, R26.1
GND: C20.2, C21.2, C23.2, C24.2, D4.2 (A), PS2.2 (GND), R24.1, R26.2; also elsewhere on the board
unnamed: C22.2, D4.1 (K), L2.1, PS2.6 (SW)
unnamed: C22.1, PS2.1 (BST)
unnamed: PS2.4 (EN), R23.1, R24.2

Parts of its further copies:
C9, C10, C32, C33, C40, C41: 10u/1206; C_0603_1608Metric; MPN C13585
C11, C34, C42: 22n; C_0603_1608Metric; MPN C21122
C12, C13, C35, C36, C43, C44: 22u; C_0603_1608Metric; MPN C45783
C14, C37, C45: 100p; C_0603_1608Metric; MPN C1790
D3, D6, D7: B340A; D_SMA; MPN C3018525
L1, L3, L4: 10u/C2921170; L_Chilisin_BMRA00040420; MPN C2921170
PS1, PS3, PS4: AP5100WG-7; SOT95P285X140-6N; Mouser Part Number 621-AP5100WG-7
R11, R13, R37, R39, R43, R45: 10k; R_0603_1608Metric; MPN C25804
R12, R38, R44: 2k; R_0603_1608Metric; MPN C22975
R14, R40, R46: 3.3k; R_0603_1608Metric; MPN C22975

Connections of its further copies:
+3.3V: C12.1, C13.1, C14.1, C35.1, C36.1, C37.1, C43.1, C44.1, C45.1, L1.2, L3.2, L4.2, R13.1, R39.1, R45.1; also elsewhere on the board
+12V: C9.1, C10.1, C32.1, C33.1, C40.1, C41.1, PS1.5 (IN), PS3.5 (IN), PS4.5 (IN), R11.2, R37.2, R43.2; also elsewhere on the board
/ControlSensorCombo/BuckStepDown/V_FB: C14.2, PS1.3 (FB), R13.2, R14.1
/LayeredEtu/BuckStepDown/V_FB: C45.2, PS4.3 (FB), R45.2, R46.1
/NormalEtu/BuckStepDown/V_FB: C37.2, PS3.3 (FB), R39.2, R40.1
GND: C9.2, C10.2, C12.2, C13.2, C32.2, C33.2, C35.2, C36.2, C40.2, C41.2, C43.2, C44.2, D3.2 (A), D6.2 (A), D7.2 (A), PS1.2 (GND), PS3.2 (GND), PS4.2 (GND), R12.1, R14.2, R38.1, R40.2, R44.1, R46.2; also elsewhere on the board
unnamed: C11.2, D3.1 (K), L1.1, PS1.6 (SW)
unnamed: C34.2, D6.1 (K), L3.1, PS3.6 (SW)
unnamed: C42.2, D7.1 (K), L4.1, PS4.6 (SW)
unnamed: C11.1, PS1.1 (BST)
unnamed: PS1.4 (EN), R11.1, R12.2
unnamed: C34.1, PS3.1 (BST)
unnamed: PS3.4 (EN), R37.1, R38.2
unnamed: C42.1, PS4.1 (BST)
unnamed: PS4.4 (EN), R43.1, R44.2


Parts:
C5: 1u; C_0603_1608Metric
C6: 10u; C_0603_1608Metric
IC2: MCP1407-E_SN; SOIC127P600X175-8N; Mouser Part Number 579-MCP1407-E/SN
Q3: SIR500DP-T1-RE3; POWERPAKSO-8
R7: 10k; R_0603_1608Metric
R8: 10R; R_1206_3216Metric

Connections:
+12V: C5.1, C6.2, IC2.1 (VDD_1), IC2.8 (VDD_2); also elsewhere on the board
/ControlSensorCombo/NMOS: IC2.2 (INPUT), R7.2; also elsewhere on the board
/ControlSensorCombo/pwr_motor: Q3.5, Q3.6, Q3.7, Q3.8, Q3.9; also elsewhere on the board
GND: C5.2, C6.1, IC2.4 (GND_1), IC2.5 (GND_2), Q3.1, Q3.2, Q3.3, R7.1; also elsewhere on the board
unnamed: IC2.6 (OUT_1), IC2.7 (OUT_2), R8.2
unnamed: Q3.4, R8.1

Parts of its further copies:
C7, C38, C50: 1u; C_0603_1608Metric
C8, C39, C51: 10u; C_0603_1608Metric
IC3, IC9, IC11: MCP1407-E_SN; SOIC127P600X175-8N; Mouser Part Number 579-MCP1407-E/SN
Q4, Q9, Q12: SIR500DP-T1-RE3; POWERPAKSO-8
R9, R41, R53: 10k; R_0603_1608Metric
R10, R42, R54: 10R; R_1206_3216Metric

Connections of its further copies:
+12V: C7.1, C8.2, C38.1, C39.2, C50.1, C51.2, IC3.1 (VDD_1), IC3.8 (VDD_2), IC9.1 (VDD_1), IC9.8 (VDD_2), IC11.1 (VDD_1), IC11.8 (VDD_2); also elsewhere on the board
/LayeredEtu/NMOS: IC11.2 (INPUT), R53.2; also elsewhere on the board
/LayeredEtu/pwr_motor: Q12.5, Q12.6, Q12.7, Q12.8, Q12.9; also elsewhere on the board
/NormalEtu/NMOS: IC9.2 (INPUT), R41.2; also elsewhere on the board
/NormalEtu/pwr_motor: Q9.5, Q9.6, Q9.7, Q9.8, Q9.9; also elsewhere on the board
/SensorRingCombo/pwr_motor_ring: Q4.5, Q4.6, Q4.7, Q4.8, Q4.9; also elsewhere on the board
/SensorRingCombo/sigIn: IC3.2 (INPUT), R9.2; also elsewhere on the board
GND: C7.2, C8.1, C38.2, C39.1, C50.2, C51.1, IC3.4 (GND_1), IC3.5 (GND_2), IC9.4 (GND_1), IC9.5 (GND_2), IC11.4 (GND_1), IC11.5 (GND_2), Q4.1, Q4.2, Q4.3, Q9.1, Q9.2, Q9.3, Q12.1, Q12.2, Q12.3, R9.1, R41.1, R53.1; also elsewhere on the board
unnamed: IC3.6 (OUT_1), IC3.7 (OUT_2), R10.2
unnamed: IC9.6 (OUT_1), IC9.7 (OUT_2), R42.2
unnamed: IC11.6 (OUT_1), IC11.7 (OUT_2), R54.2
unnamed: Q4.4, R10.1
unnamed: Q9.4, R42.1
unnamed: Q12.4, R54.1



Board: 2 copper layers, 158.9 x 117.1 mm, 193 parts (35 on the bottom side), 74 nets.

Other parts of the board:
U18: Gnd; Copper_Pad
U19: 12v; Copper_Pad

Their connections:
+12V: U19.1 (Con); also elsewhere on the board
/SensorRingCombo/pwr_motor_ring: U18.1 (Con); also elsewhere on the board

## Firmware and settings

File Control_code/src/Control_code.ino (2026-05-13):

#include <Arduino.h>
#include <EEPROM.h>

#ifndef MOTOR_DUTY
#define MOTOR_DUTY 100
#endif

#ifndef DEAD_TIME_TICKS
#define DEAD_TIME_TICKS 2
#endif

#define DEADTIME400 __asm__ __volatile__ ("nop \n\t""nop \n\t""nop \n\t""nop \n\t""nop \n\t""nop \n\t""nop \n\t""nop \n\t")

// --- Pins ---
// FOR ATTINY814 ( in_development_ETU_AIO)
#define  TRIGGER   PIN_PB1
#define CYCLE     PIN_PA1
#define MODE      PIN_PB0
//PIN PA4 and PA5 used for output
// --- Data Structures ---

enum modeStates{
  SEMI,
  AUTO,
  BURST,
  BINARY
};

enum state{
  STANDBY,
  MOTORSTART,
  MOTORFULLPOWER,
  MOTORSTOP
};

struct selector {
  enum modeStates pos1 = SEMI;
  enum modeStates pos2 = AUTO;
};

// --- Logic Variables ---
volatile uint8_t burstCounter = 0;
bool hasBraked = true;
selector modes;
enum modeStates selectorState;
enum state motorState = STANDBY;

// --- Time Variables ---
const unsigned long motorJamTimeout = 500;
unsigned long motorJamTime = 0;
const unsigned long motorBrakeTimeout = 1000;
unsigned long motorBrakeTime = 0;

// --- TCD0 Config ---

static uint8_t TCD_PERIOD_TICKS = 156;
static uint8_t TCD_DRIVE_TICKS = ((TCD_PERIOD_TICKS * MOTOR_DUTY) / 100 >  TCD_PERIOD_TICKS - 2 * DEAD_TIME_TICKS - 2) ? TCD_PERIOD_TICKS - 2 * DEAD_TIME_TICKS - 2 : (TCD_PERIOD_TICKS * MOTOR_DUTY) / 100;
static uint8_t TCD_CMPASET_VAL = DEAD_TIME_TICKS-1;
static uint8_t TCD_CMPACLR_VAL = DEAD_TIME_TICKS +  TCD_DRIVE_TICKS-1;
static uint8_t TCD_CMPBSET_VAL = 2 * DEAD_TIME_TICKS + TCD_DRIVE_TICKS-1;
static uint8_t TCD_CMPBCLR_VAL = TCD_PERIOD_TICKS-1;


void TCD0_clear(){
  TCD0.CTRLA = 0;
  while (!(TCD0.STATUS & TCD_ENRDY_bm)) {}
  TCD0.CTRLC      = 0;
  TCD0.CTRLD      = 0;
  TCD0.CTRLE      = 0;
  TCD0.INPUTCTRLA = 0;
  TCD0.INPUTCTRLB = 0;
  TCD0.EVCTRLA    = 0;
  TCD0.EVCTRLB    = 0;
  TCD0.DLYCTRL    = 0;
}

void TCD0_init()
{    
  TCD0_clear();
  TCD0.CTRLB = TCD_WGMODE_ONERAMP_gc;
  TCD0.CMPASET = TCD_CMPASET_VAL;
  TCD0.CMPACLR = TCD_CMPACLR_VAL;
  TCD0.CMPBSET = TCD_CMPBSET_VAL;
  TCD0.CMPBCLR = TCD_CMPBCLR_VAL;
  _PROTECTED_WRITE(TCD0.FAULTCTRL, 0);

  TCD0.CTRLA = TCD_CLKSEL_SYSCLK_gc | TCD_SYNCPRES_DIV1_gc | TCD_CNTPRES_DIV4_gc;
}

void PORT_init()
{
  PORTMUX.CTRLC = 0;
  PORTA.OUTCLR = PIN4_bm | PIN5_bm;
  PORTA.PIN5CTRL |= PORT_INVEN_bm;
  PORTA.DIRSET = PIN4_bm | PIN5_bm;

}

void change_settings(){

}

void setup() {
    // Input Init
  pinMode(TRIGGER, INPUT);
  pinMode(CYCLE, INPUT);
  pinMode(MODE, INPUT);

  if (digitalRead(TRIGGER)==HIGH) change_settings(); //implement settings

  // Output Init
  PORT_init();
  if(MOTOR_DUTY < 90) TCD0_init();


  // Selector init
  // Temp comment for debugging
  // mode_change();
  selectorState = SEMI;

  // Interrupts init
  attachInterrupt(digitalPinToInterrupt(TRIGGER),  trigger_pressed, RISING);
  attachInterrupt(digitalPinToInterrupt(CYCLE), cycle_completed, RISING);
  // Temp comment for debugging
  // attachInterrupt(digitalPinToInterrupt(MODE), mode_change, CHANGE);
}

void  trigger_pressed() {
  if (motorState == STANDBY) {
    burstCounter = 0;
    motorState = MOTORSTART;
  }
}

void cycle_completed() {
  if (motorState == MOTORFULLPOWER) {
    if (selectorState == BURST) burstCounter++;
    motorJamTime = millis();
    motorState = MOTORSTOP;
  }
}

void mode_change() {
  if (digitalRead(MODE) == HIGH) {
    selectorState = modes.pos2;
  } else {
    selectorState = modes.pos1;
  }
}

void motor_on() {
  PORTA.OUTCLR = PIN4_bm | PIN5_bm;
  
  DEADTIME400;

  if(MOTOR_DUTY<90){
    _PROTECTED_WRITE(TCD0.FAULTCTRL, TCD_CMPAEN_bm | TCD_CMPBEN_bm);
    while (!(TCD0.STATUS & TCD_ENRDY_bm)) {}
    TCD0.CTRLA |= TCD_ENABLE_bm;
  } else PORTA.OUTSET = PIN4_bm;

  motorState = MOTORFULLPOWER;
  motorJamTime = millis();
}

void motor_off(){
  PORTA.OUTCLR = (PIN4_bm | PIN5_bm);

  if(MOTOR_DUTY < 90){
    while (!(TCD0.STATUS & TCD_ENRDY_bm)) {}
    TCD0.CTRLA &= ~TCD_ENABLE_bm;
    while (!(TCD0.STATUS & TCD_ENRDY_bm)) {}
    _PROTECTED_WRITE(TCD0.FAULTCTRL, 0);
  }

  DEADTIME400;
  
  PORTA.OUTCLR = PIN4_bm;
  PORTA.OUTSET = PIN5_bm;
  //add delay till break stop
  motorBrakeTime = millis();
  hasBraked = false;
  motorState = STANDBY;
}

void modes_decision(){
  motorState = MOTORFULLPOWER;
  switch (selectorState){
    case SEMI:
      motor_off();
    break;
    case AUTO:
      if(digitalRead( TRIGGER) == HIGH) motor_off();
    break;
    case BURST:
      if(digitalRead( TRIGGER) == HIGH) motor_off();
      else if(burstCounter >= 3) motor_off();
    break;
  }
}

void loop() {
  if (motorState == MOTORSTART) motor_on();
  else if (motorState == MOTORSTOP) modes_decision();

  if(!hasBraked && millis()-motorBrakeTime > motorBrakeTimeout){
   //Clear high side mos after 1 second
   PORTA.OUTCLR = PIN5_bm;
   hasBraked=true;
  }

  // Disabled for debugging purposes
  // if (motorState == MOTORFULLPOWER && (millis() - motorJamTime > motorJamTimeout)) {
  //  // The motor has been running for too long, indicating a jam
  //  motor_off();
  //  while(true){;} //Power cycle required to shoot again
  // }
}

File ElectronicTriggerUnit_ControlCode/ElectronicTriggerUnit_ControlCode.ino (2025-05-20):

//motor states
#define STANDBY 0
#define MOTORENABLE 1
#define MOTORFULLPOWER 2
#define MOTORDISABLE 3
//selector states
#define SEMI 0
#define AUTO 1
////pins

// FOR ATTINY816 ( latest stable)
// int triggerPin = PIN_PB0;
// int cyclePin = PIN_PA1;
// int modePin = PIN_PB1;
// int motorGroundPlane = PIN_PA5;

// FOR ATTINY814 ( in_development )
int triggerPin = PIN_PB0;
int cyclePin = PIN_PA1;
int modePin = PIN_PB1;
int motorGroundPlane = PIN_PA5;
//logic
volatile int motorState = STANDBY;
int selectorState;
//debounceTiming
volatile unsigned long last_millis = 0;


void setup() {
  //Input Init
  pinMode(triggerPin, INPUT);
  pinMode(cyclePin, INPUT);
  pinMode(modePin, INPUT);
  //Output Init
  pinMode(motorGroundPlane, OUTPUT);
  digitalWrite(motorGroundPlane,LOW);
  //Parameters init
  // selectorState=SEMI; //uncomment if you don't want/don't have a fire mode selector and comment the next line
  mode_change();
  //Interrupts init
  attachInterrupt(digitalPinToInterrupt(triggerPin), flag_trigger, FALLING);
  attachInterrupt(digitalPinToInterrupt(cyclePin), flag_cycle, RISING);
  attachInterrupt(digitalPinToInterrupt(modePin), mode_change, CHANGE); // comment if you don't want/don't have a fire mode selector
}

void flag_trigger() {
  if (motorState == STANDBY)
    motorState = MOTORENABLE;
}

void flag_cycle() {
  if (motorState == MOTORFULLPOWER)
    motorState = MOTORDISABLE;
}

void mode_change(){
  if(modePin == HIGH) selectorState = AUTO;
  else selectorState = SEMI;
}

void motor_on() {
  digitalWrite(motorGroundPlane, HIGH);
  motorState = MOTORFULLPOWER;
}

void motor_off() {
  switch (selectorState) {
    case SEMI:
      digitalWrite(motorGroundPlane, LOW);
      motorState = STANDBY;
      break;
    case AUTO:
      if (digitalRead(triggerPin) == HIGH) {
        digitalWrite(motorGroundPlane, LOW);
        motorState = STANDBY;
      }
      break;
  }
}

void loop() {
  if (motorState == MOTORENABLE) motor_on();
  else if (motorState == MOTORDISABLE) motor_off();
}

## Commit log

2025-05-07 changed some parts
    [ElectronicTriggerUnit.kicad_pcb, ElectronicTriggerUnit.kicad_sch]
2025-05-09 redid ground plane and trace spacing
    [ElectronicTriggerUnit.kicad_pcb, ElectronicTriggerUnit.kicad_sch]
2025-05-12 added motor ring
    [ElectronicTriggerUnit.kicad_pcb, ElectronicTriggerUnit.kicad_sch]
2025-05-14 outputs of gate driver needed to be shorted :(
    [ElectronicTriggerUnit.kicad_pcb, ElectronicTriggerUnit.kicad_sch]
2025-05-20 updated code , modified resistors
    [ElectronicTriggerUnit.kicad_pcb, ElectronicTriggerUnit.kicad_sch]
2025-05-21 added a different combo
    [ElectronicTriggerUnit.kicad_pcb, ElectronicTriggerUnit.kicad_sch, buck.kicad_sch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]
2025-05-23 small fixes for new combo
    [ElectronicTriggerUnit.kicad_pcb, sensor_ring.kicad_sch]
2025-09-04 moved to platformio
    [ElectronicTriggerUnit.kicad_pcb, ElectronicTriggerUnit.kicad_sch, buck.kicad_sch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]
2025-09-04 added settings , burst mode , and basic failsafe.
    [Control_code.ino]
2026-01-12 stacked version
    [ElectronicTriggerUnit.kicad_pcb, ElectronicTriggerUnit.kicad_sch, ElectronicTriggerUnit.step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]
2026-02-08 Parting off each design into a project
    [Driver.kicad_pcb, Driver.kicad_sch]
2026-04-28 more boards for testing
    [ETU_AIO.kicad_pcb, ETU_AIO.kicad_sch, ETU_AIO.step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]
